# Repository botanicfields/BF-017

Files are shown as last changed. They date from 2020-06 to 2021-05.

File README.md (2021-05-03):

# BF-017
タイマーIC 555をディスクリート・トランジスタで作る基板

頒布(Martket place):
https://www.switch-science.com/catalog/6433/

Qiitaに説明があります。
https://qiita.com/BotanicFields/items/ccec29255a49967116c1

GitHubに資料があります。
https://github.com/botanicfields/BF-017

AkiCart:
https://aki.prioris.jp/list/0b58d2fc-eee4-429c-9d86-0e2e1c66c018/

### はじめに
　古典的なタイマーICである555の内部回路を、単体（ディスクリート）トランジスタで実現するプリント基板を作成しました。中国の製造業者がプリント基板を安価かつ短納期で試作してくれます。個人でもプリント基板の設計発注が容易になっていて、555はトレーニングに適切な題材と思いました。

### 工夫点
　オシロスコープによる波形観測を容易にするためにテストポイントを設けます。トランジスタや抵抗などの部品の足やパッドから信号を取り出す必要がなくなり部品を比較的詰めて配置できます。
 
### お詫び
　プリント基板のシルク印刷でQ10, Q11, Q12, Q13の位置を間違えています。幸い、いずれも同じPNPトランジスタなので結果的に組立時には問題にはなりません。
V01L02で修正しました。資料は訂正済のものです。正しくは資料を参照ください。

https://github.com/botanicfields/BF-017/blob/master/BF-017_POS.pdf

### 提供元
BotanicFields, Inc.

https://www.facebook.com/botanicfields/

https://twitter.com/botanicfields

2020年6月22日

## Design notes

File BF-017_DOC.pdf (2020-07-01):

単体トランジスタでつくる NE555

1. はじめに
古典的なタイマーIC である 555 の内部回路を、単体（ディスクリート）トランジスタで実現するプ リント基板を作成しました。中国の製造業者がプリント基板を安価かつ短納期で試作してくれます。個 人でもプリント基板の設計発注が容易になっていて、555 はトレーニングに適切な題材と思いました。
2. 工夫点
オシロスコープによる波形観測を容易にするためにテストポイントを設けます。トランジスタや抵抗 などの部品の足やパッドから信号を取り出す必要がなくなり部品を比較的詰めて配置できます。
3. 組立
プリント基板のシルク印刷に抵抗値等がありません。回路図および組み立て図を参照しながらの作業 になります。背の低い部品から順にハンダ付けしていきます。抵抗、コンデンサ、テストポイント、ピ ンヘッダ、トランジスタの順がよいと思います。
4. お詫び(V01L01)
プリント基板(V01L01)のシルク印刷で Q10, Q11, Q12, Q13 の位置を間違えています。幸い、いずれ も同じ PNP トランジスタなので結果的に組立時には問題になりません。 資料は訂正済のものです。正 しくは資料を参照ください。プリント基板(V01L02)で修正しています。

資料
Qiita：タイマーIC NE555 をディスクリート・トランジスタでつくる https://qiita.com/BotanicFields/items/ccec29255a49967116c1

GitHub: botanicfields/BF-017 https://github.com/botanicfields/BF-017

提供元
BotanicFields, Inc.
https://www.facebook.com/botanicfields/https://twitter.com/botanicfields
2020 年 7 月 2 日

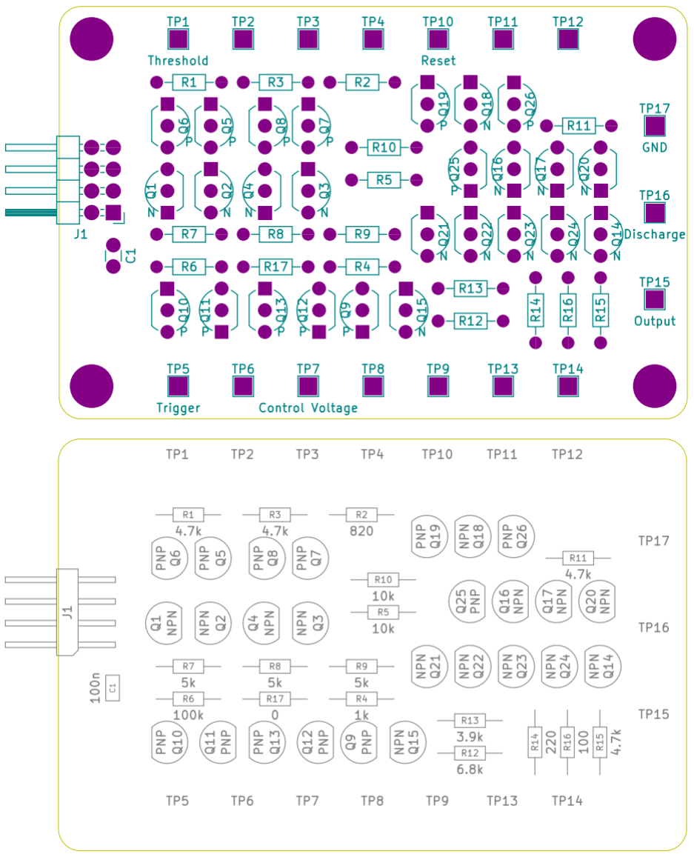
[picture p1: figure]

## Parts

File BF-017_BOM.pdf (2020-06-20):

Copyright 2020 BotanicFields, Inc.

BF-017 部品表 | 2020/6/20
No. | Reference | Quantity | Value | 部品の例：秋月電子通商での商品名 | 秋月電子の通販コード
1 | Q1 Q2 Q3 Q4 Q14 Q15 Q16 Q17 Q18 Q20 Q21 Q22 Q23 Q24 | 14 | NPN | トランジスタ ２ＳＣ１８１５ＬＧＲＴ９２Ｋ ６０Ｖ１５０ｍＡ （２０個入） | I-06477
2 | Q5 Q6 Q7 Q8 Q9 Q10 Q11 Q12 Q13 Q19 Q25 Q26 | 12 | PNP | トランジスタ ２ＳＡ１０１５ＬＧＲＴ９２Ｋ ５０Ｖ１５０ｍＡ （２０個入） | I-06734
3 | R17 | 1 | 0 | カーボン抵抗（炭素皮膜抵抗） １／６Ｗ０Ω （１００本入） | R-16000
4 | R16 | 1 | 100 | カーボン抵抗（炭素皮膜抵抗） １／６Ｗ１００Ω （１００本入） | R-16101
5 | R14 | 1 | 220 | カーボン抵抗（炭素皮膜抵抗） １／６Ｗ２２０Ω （１００本入） | R-16221
6 | R2 | 1 | 820 | カーボン抵抗（炭素皮膜抵抗） １／６Ｗ８２０Ω （１００本入） | R-16821
7 | R4 | 1 | 1k | カーボン抵抗（炭素皮膜抵抗） １／６Ｗ１ｋΩ （１００本入） | R-16102
8 | R13 | 1 | 3.9k | カーボン抵抗（炭素皮膜抵抗） １／６Ｗ３．９ｋΩ （１００本入） | R-16392
9 | R1 R3 R11 R15 | 4 | 4.7k | カーボン抵抗（炭素皮膜抵抗） １／６Ｗ４．７ｋΩ （１００本入） | R-16472
10 | R7 R8 R9 | 3 | 5k | カーボン抵抗（炭素皮膜抵抗） １／６Ｗ５．１ｋΩ （１００本入） | R-16512
11 | R12 | 1 | 6.8k | カーボン抵抗（炭素皮膜抵抗） １／６Ｗ６．８ｋΩ （１００本入） | R-16682
12 | R5 R10 | 2 | 10k | カーボン抵抗（炭素皮膜抵抗） １／６Ｗ１０ｋΩ （１００本入） | R-16103
13 | R6 | 1 | 100k | カーボン抵抗（炭素皮膜抵抗） １／６Ｗ１００ｋΩ （１００本入） | R-16104
14 | C1 | 1 | 100n | 絶縁ラジアルリード型積層セラミックコンデンサー ０．１μＦ５０Ｖ±１０％２．５４ｍｍ （１０個入） | P-04064
15 | TP1 TP2 TP3 TP4 TP5 TP6 TP7 TP8 TP9 TP10 TP11 TP12 TP13 TP14 TP15 TP16 TP17 | 17 | TestPoint | チェック端子 ＴＥＳＴ１ （１０個入） | 赤：P-07588 緑：P-07589 青：P-07590 黒：P-07591 黄：P-07592 白：P-07593
16 | J1 | 1 | 2x4 | ピンヘッダ （オスＬ型） ２×１０ （２０Ｐ） | C-10903

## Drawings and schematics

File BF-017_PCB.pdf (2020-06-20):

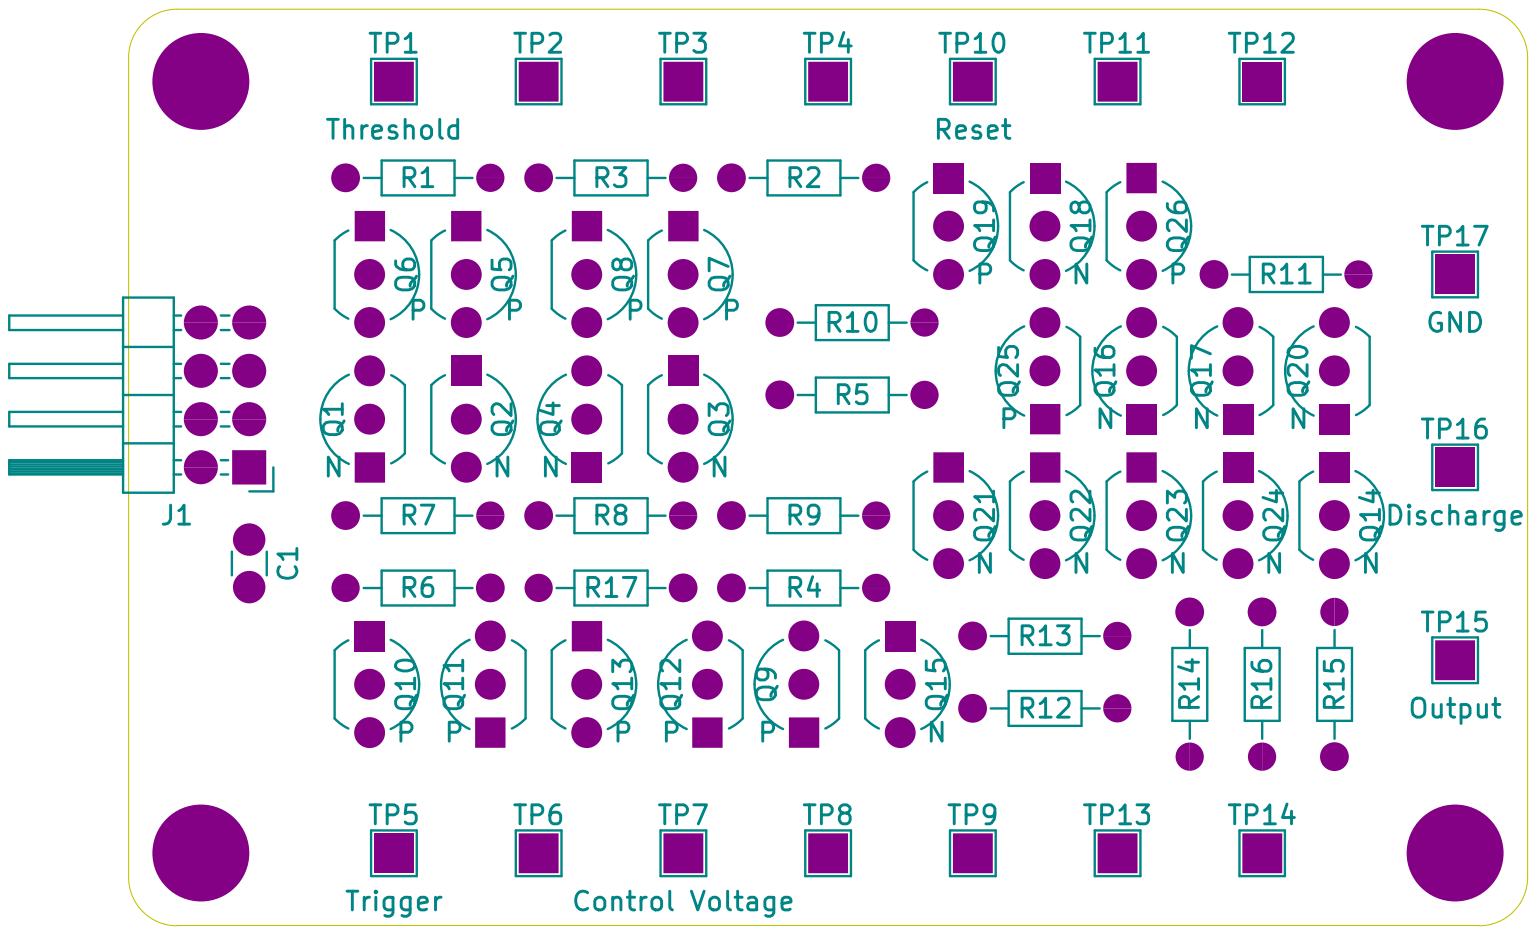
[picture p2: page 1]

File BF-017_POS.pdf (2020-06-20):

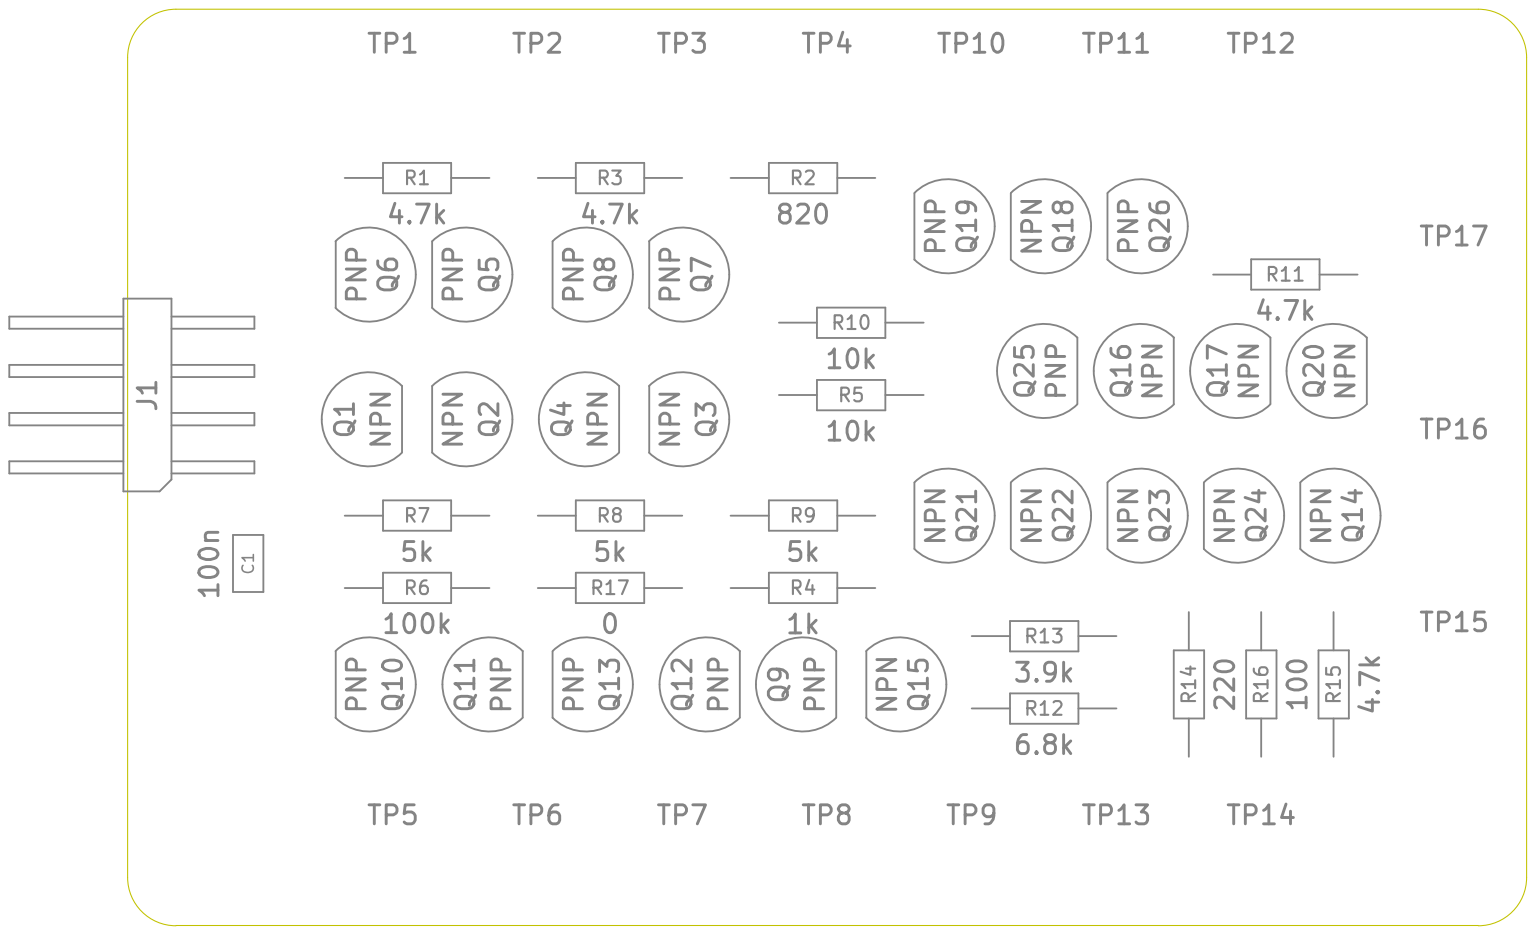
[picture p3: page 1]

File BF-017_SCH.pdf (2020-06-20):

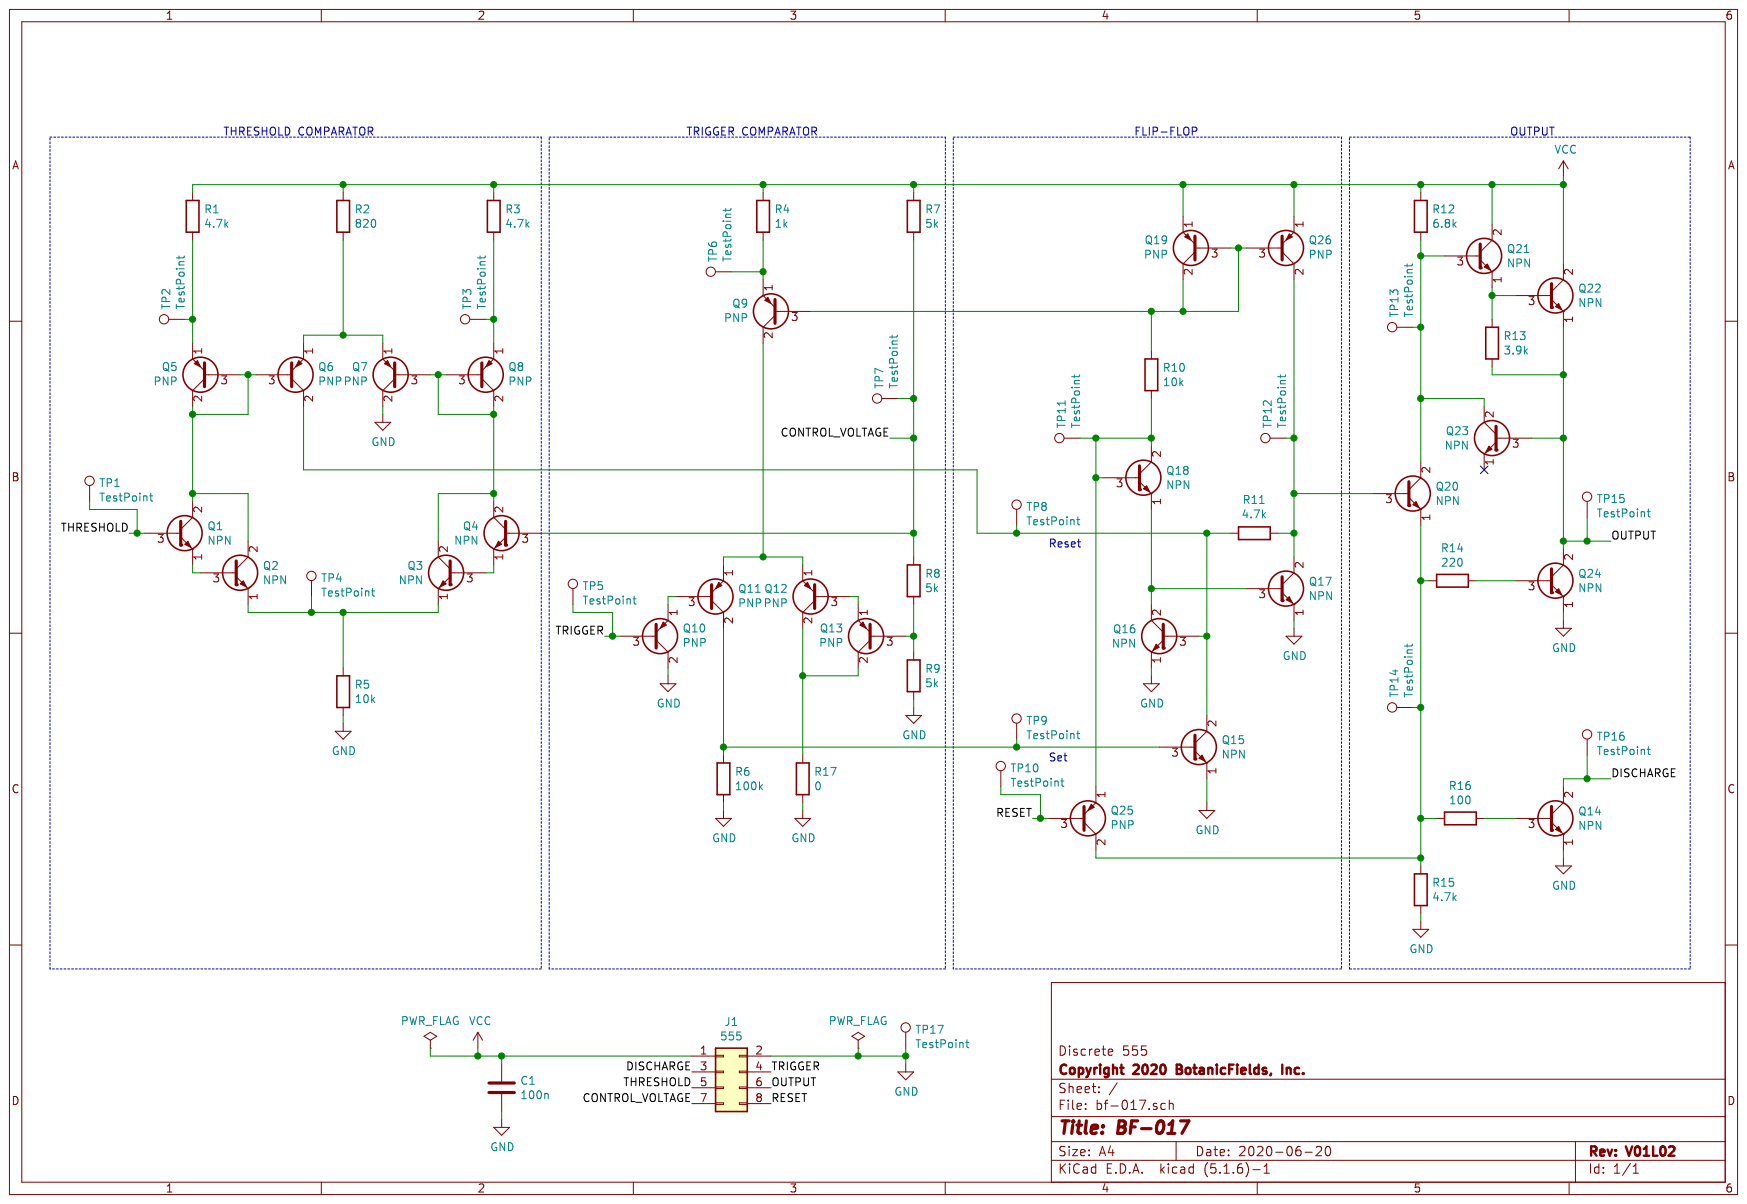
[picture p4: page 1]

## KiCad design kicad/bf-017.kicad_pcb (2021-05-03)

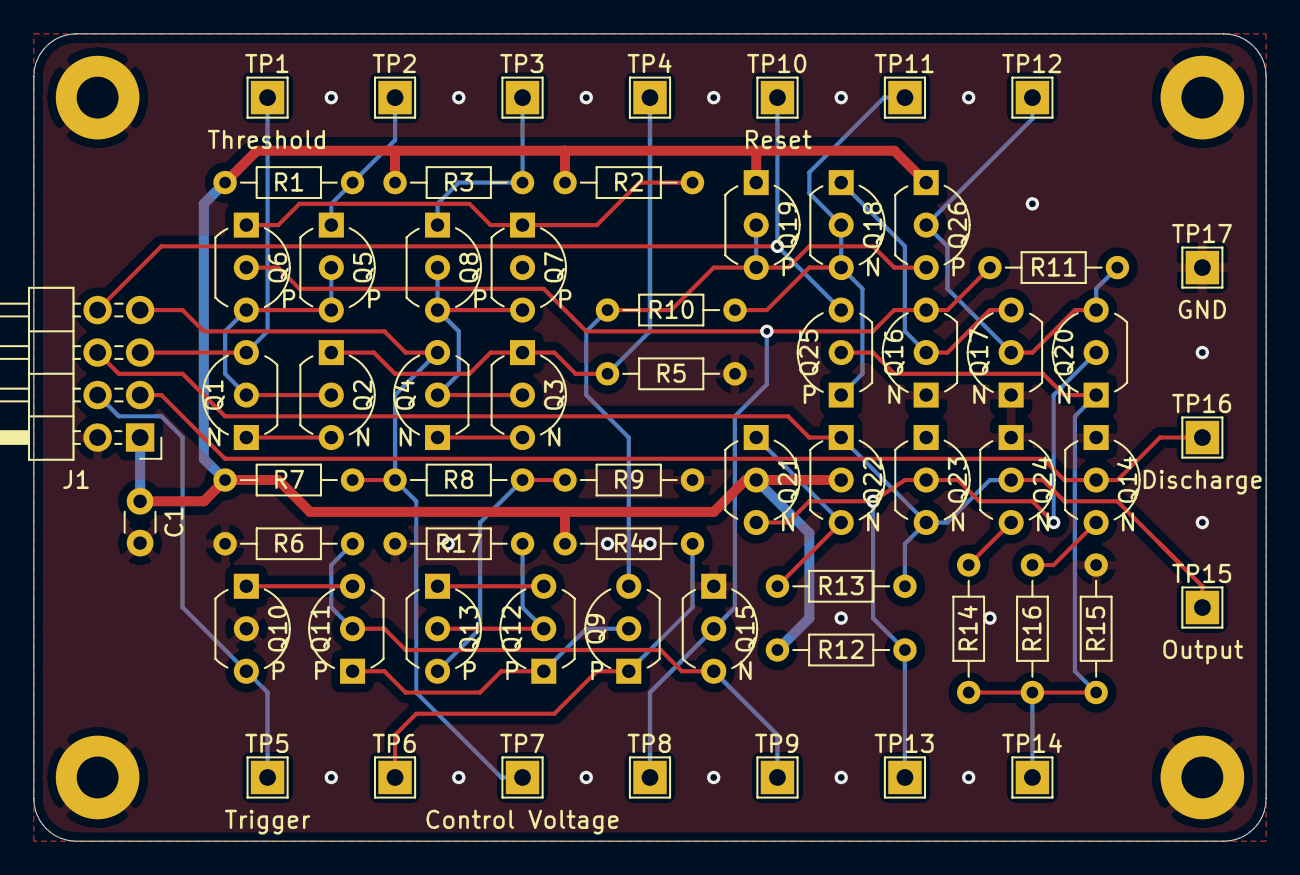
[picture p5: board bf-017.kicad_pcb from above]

Board: 2 copper layers, 73.7 x 48.3 mm, 62 parts (0 on the bottom side), 33 nets.

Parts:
C1: 100n; C_Disc_D3.0mm_W1.6mm_P2.50mm
J1: 555; PinHeader_2x04_P2.54mm_Horizontal
Q1, Q2, Q3, Q4, Q14, Q15, Q16, Q17, Q18, Q20, Q21, Q22, Q23, Q24: NPN; TO-92_Inline_Wide
Q5, Q6, Q7, Q8, Q9, Q10, Q11, Q12, Q13, Q19, Q25, Q26: PNP; TO-92_Inline_Wide
R1, R3, R11, R15: 4.7k; R_Axial_DIN0204_L3.6mm_D1.6mm_P7.62mm_Horizontal
R2: 820; R_Axial_DIN0204_L3.6mm_D1.6mm_P7.62mm_Horizontal
R4: 1k; R_Axial_DIN0204_L3.6mm_D1.6mm_P7.62mm_Horizontal
R5, R10: 10k; R_Axial_DIN0204_L3.6mm_D1.6mm_P7.62mm_Horizontal
R6: 100k; R_Axial_DIN0204_L3.6mm_D1.6mm_P7.62mm_Horizontal
R7, R8, R9: 5k; R_Axial_DIN0204_L3.6mm_D1.6mm_P7.62mm_Horizontal
R12: 6.8k; R_Axial_DIN0204_L3.6mm_D1.6mm_P7.62mm_Horizontal
R13: 3.9k; R_Axial_DIN0204_L3.6mm_D1.6mm_P7.62mm_Horizontal
R14: 220; R_Axial_DIN0204_L3.6mm_D1.6mm_P7.62mm_Horizontal
R16: 100; R_Axial_DIN0204_L3.6mm_D1.6mm_P7.62mm_Horizontal
R17: 0; R_Axial_DIN0204_L3.6mm_D1.6mm_P7.62mm_Horizontal
TP1, TP2, TP3, TP4, TP5, TP6, TP7, TP8, TP9, TP10, TP11, TP12, TP13, TP14, TP15, TP16, TP17: TestPoint; TestPoint_THTPad_2.0x2.0mm_Drill1.0mm

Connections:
/CONTROL_VOLTAGE: J1.7, Q4.3, R7.2, R8.1, TP7.1
/DISCHARGE: J1.3, Q14.2, TP16.1
/OUTPUT: J1.6, Q22.1, Q23.3, Q24.2, R13.2, TP15.1
/RESET: J1.8, Q25.3, TP10.1
/THRESHOLD: J1.5, Q1.3, TP1.1
/TRIGGER: J1.4, Q10.3, TP5.1
GND: C1.2, J1.2, Q7.2, Q10.2, Q14.1, Q15.1, Q16.1, Q17.1, Q24.1, R5.2, R6.2, R9.2, R15.2, R17.2, TP17.1
unnamed: Q1.1, Q2.3
unnamed: Q1.2, Q2.2, Q5.2, Q5.3, Q6.3
unnamed: Q2.1, Q3.1, R5.1, TP4.1
unnamed: Q3.2, Q4.2, Q7.3, Q8.2, Q8.3
unnamed: Q3.3, Q4.1
unnamed: Q5.1, R1.2, TP2.1
unnamed: Q6.1, Q7.1, R2.2
unnamed: Q8.1, R3.2, TP3.1
unnamed: Q9.1, R4.2, TP6.1
unnamed: Q10.1, Q11.3
unnamed: Q9.2, Q11.1, Q12.1
unnamed: Q11.2, Q15.3, R6.1, TP9.1
unnamed: Q12.2, Q13.2, R17.1
unnamed: Q12.3, Q13.1
unnamed: Q13.3, R8.2, R9.1
unnamed: Q14.3, R16.1
unnamed: Q6.2, Q15.2, Q16.3, R11.1, TP8.1
unnamed: Q16.2, Q17.3, Q18.1
unnamed: Q17.2, Q20.3, Q26.2, R11.2, TP12.1
unnamed: Q18.2, Q18.3, Q25.1, R10.2, TP11.1
unnamed: Q9.3, Q19.2, Q19.3, Q26.3, R10.1
unnamed: Q20.1, Q25.2, R14.2, R15.1, R16.2, TP14.1
unnamed: Q20.2, Q21.3, Q23.2, R12.2, TP13.1
unnamed: Q21.1, Q22.3, R13.1
unnamed: Q24.3, R14.1
VCC: C1.1, J1.1, Q19.1, Q21.2, Q22.2, Q26.1, R1.1, R2.1, R3.1, R4.1, R7.1, R12.1

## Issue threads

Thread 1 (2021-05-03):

Gerbers

lafkyc, 2021-05-03:
Would you be willing to share gerbers? I would love to just have one made to play with in my lab

uehara00, 2021-05-03:
I uploaded the gerber and kicad files(sch and pcb) now.
The board is sold at a market place in Japan.
https://www.switch-science.com/catalog/6433/
Please enjoy!

lafkyc, 2021-05-03:
Thank you much! I have never seen that website before either looks cool :)

Closed 2021-05-03.
